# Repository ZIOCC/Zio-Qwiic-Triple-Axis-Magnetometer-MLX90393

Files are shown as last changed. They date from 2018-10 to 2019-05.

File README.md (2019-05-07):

# Zio Qwiic Triple Axis Magnetometer (MLX90393)

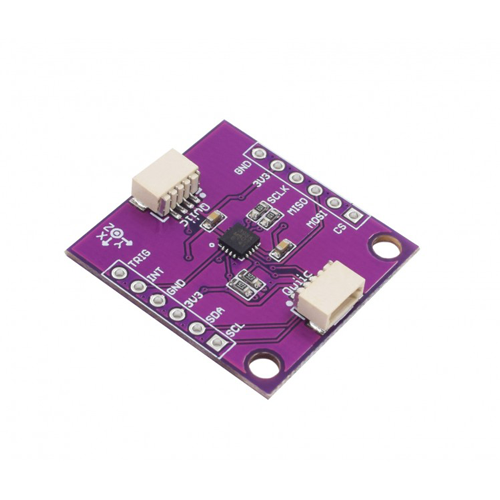
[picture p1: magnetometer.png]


> This product can be available for purchase [here](https://www.smart-prototyping.com/Zio-QwiIc-Triple-Axis-Magnetometer-MLX90393).

#### Description

This ZIO Qwiic board can be used as one of the Four Great Inventions: the compass. The board is a triple-axis magnetometer compass used to detect magnetic forces, mostly used to detect magnetic North. 
But magnetometers have many other uses such as detecting magnetic materials. 
 
The board features a MLX90393 sensor that incorporates both I2C and, able to sense a wide range of fields from small ones such as Earth’s magnetic field to larger magnetic fields. But the compass is not the only application for it, it can also be used for non-contact HMI applications (such as rotary knobs and joysticks), home security, liquid level sensing, position sensing and magnetic fingerprint detection. 
 
The resolution rate for the sensor is 0.161µ with an operating voltage range of 2.2V to 3.6V at 100µA. 
In addition, the I2C address can be changed thanks to the jumper pads on the back of the board (A0/ A1)  and the mode can also be changed to SPI thought the jumper pads. 

#### Specification

* Operation Voltage: 2.2V to 3.3V
* Relative Humidity: ±2%
* Temperature: ±0.3 °C
* IC: MLX90393
* I2C address: 0x0C, 0x0D, 0x0E, 0x0F (Default: 0x0C)
* Dimensions: 25.5 x 26.8mm
* Weight: 1.6g

#### Links

* [PCB source file (eagle file, schematic, Gerber files)](https://github.com/ZIOCC/Zio-Qwiic-Triple-Axis-Magnetometer-MLX90393)
* [MLX90393 Datasheet](https://cdn.sparkfun.com/assets/e/e/f/2/7/MLX90393-Datasheet-Melexis.PDF)
* [Library Code](https://github.com/tedyapo/arduino-MLX90393)

> ###### About Zio
> Zio is a new line of open sourced, compact, and grid layout boards, fully integrated for Arduino and Qwiic ecosystem. Designed ideally for wearables, robotics, small-space limitations or other on the go projects. Check out other awesome Zio products [here](https://www.smart-prototyping.com/Zio).

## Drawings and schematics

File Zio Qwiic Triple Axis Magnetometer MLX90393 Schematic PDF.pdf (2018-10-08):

# +3V3INT

1 | 2 | 3 | 4

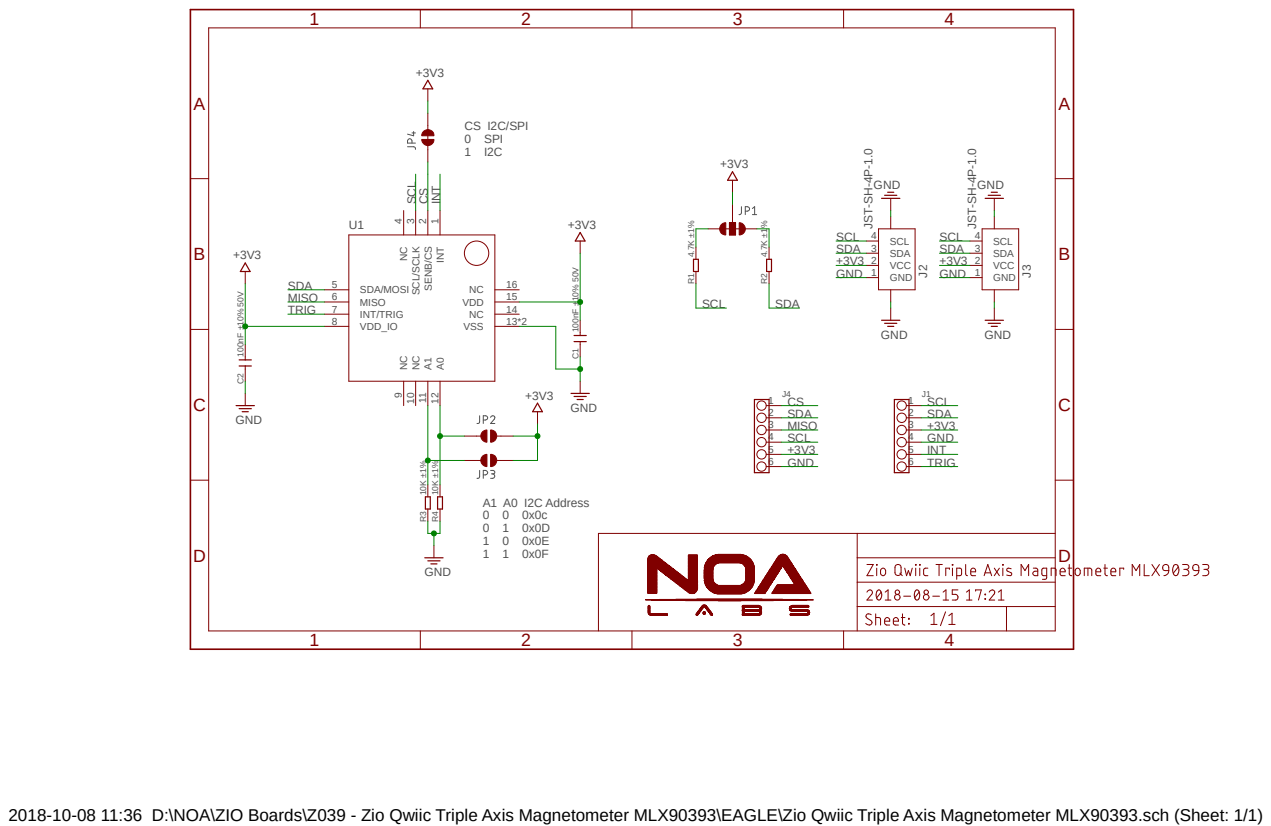
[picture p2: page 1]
A1 A0 I2C Address 0 0 0x0c 0 1 0x0D 1 0 0x0E 1 1 0x0F; CS I2C/SPI 0 SPI 1 I2C; GND; GND 4.7K ±1%; 100nF ±10% ⁵⁰V; GND¹⁰⁰nF ±10% ⁵⁰V; 1 SENB/CS; 2 SCL/SCLK; SDA/MOSI 5 MISO 6 INT/TRIG 7; VDD_IO 8; VSS; 14 VDD; GND 1; VCC 2; SDA 3; SCL 4; J3 JST⁻SH⁻⁴P⁻¹.0; J2 JST⁻SH⁻⁴P⁻¹.0 R¹; SCL; SCL SCL; SDA; +3V3 INT; INT; MISO; TRIG; TRIG CS

2018-10-08 11:36 D:\NOA\ZIO Boards\Z039 - Zio Qwiic Triple Axis Magnetometer MLX90393\EAGLE\Zio Qwiic Triple Axis Magnetometer MLX90393.sch (Sheet: 1/1)

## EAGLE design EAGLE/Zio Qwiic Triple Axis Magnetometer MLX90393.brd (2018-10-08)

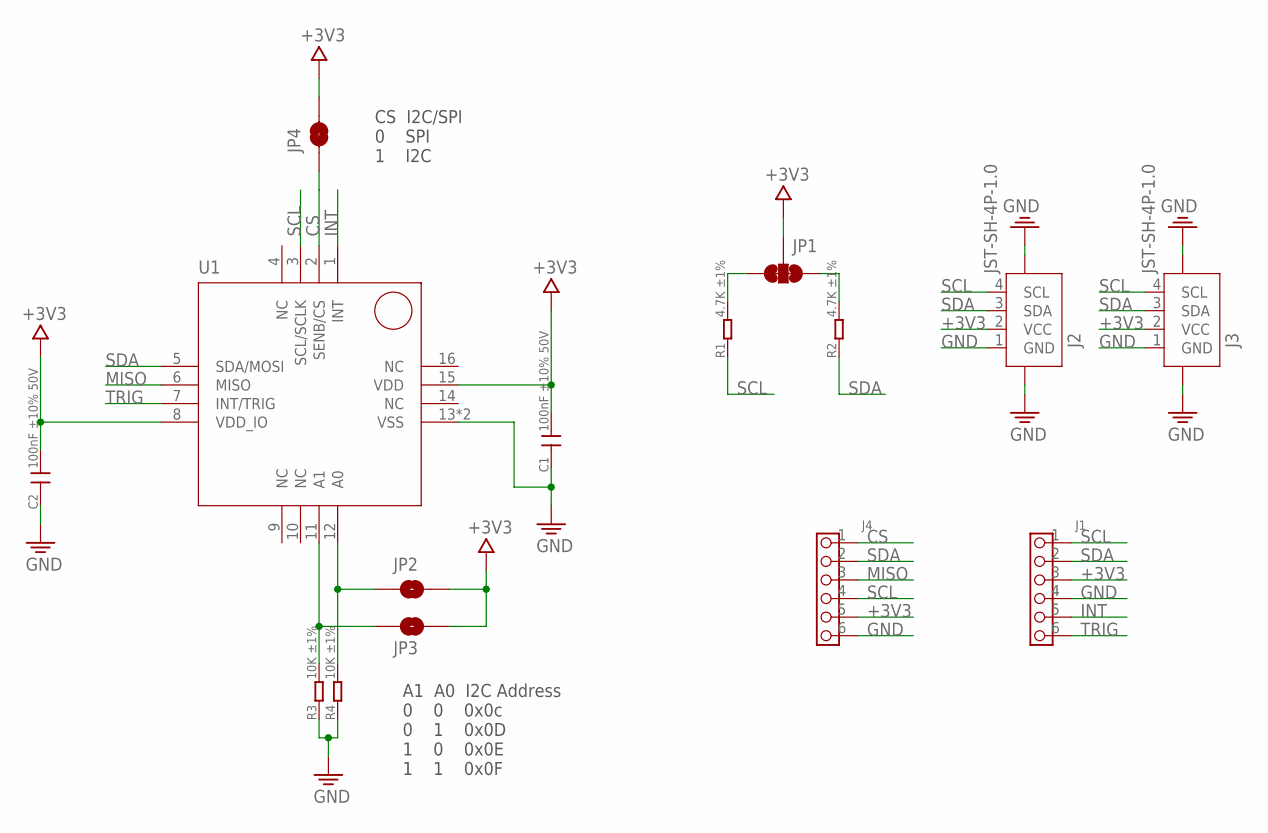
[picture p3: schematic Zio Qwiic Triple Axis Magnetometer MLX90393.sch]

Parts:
C1, C2: 100nF ±10% 50V; C0603
J1, J4: HEADER-6P-60/35MIL; 6P-2.54-60/35MIL
J2, J3: JST-SH-4P-1.0; JST-SH-4P
JP1: SMT-JUMPER_3_2-NC_TRACE
JP2, JP3: JUMPER-SMT_2_NC_PASTE_NOCREM; SMT-JUMPER_2_NC_PASTE_SILK_NOCREM
JP4: JUMPER-SMT_2_NC_TRACE; SMT-JUMPER_2_NC_TRACE
R1, R2: 4.7K ±1%; R0603
R3, R4: 10K ±1%; R0603
U1: MLX90393; QFN16-3*3

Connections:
+3V3: C1.2, C2.2, J1.3, J2.2 (VCC), J3.2 (VCC), J4.5, JP1.2, JP2.2, JP3.2, JP4.2, U1.8 (VDD_IO), U1.15 (VDD)
CS: J4.1, JP4.1, U1.2 (SENB/CS)
GND: C1.1, C2.1, J1.4, J2.1 (GND), J2.NC1 (5), J2.NC2 (6), J3.1 (GND), J3.NC1 (5), J3.NC2 (6), J4.6, R3.1, R4.1, U1.13 (VSS), U1.PAD (VSS)
INT: J1.5, U1.1 (INT)
MISO: J4.3, U1.6 (MISO)
unnamed: JP3.1, R3.2, U1.11 (A1)
unnamed: JP2.1, R4.2, U1.12 (A0)
unnamed: JP1.3, R1.2
unnamed: JP1.1, R2.2
SCL: J1.1, J2.4 (SCL), J3.4 (SCL), J4.4, R1.1, U1.3 (SCL/SCLK)
SDA: J1.2, J2.3 (SDA), J3.3 (SDA), J4.2, R2.1, U1.5 (SDA/MOSI)
TRIG: J1.6, U1.7 (INT/TRIG)

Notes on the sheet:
A1 A0 I2C Address 0 0 0x0c 0 1 0x0D 1 0 0x0E 1 1 0x0F
CS I2C/SPI 0 SPI 1 I2C

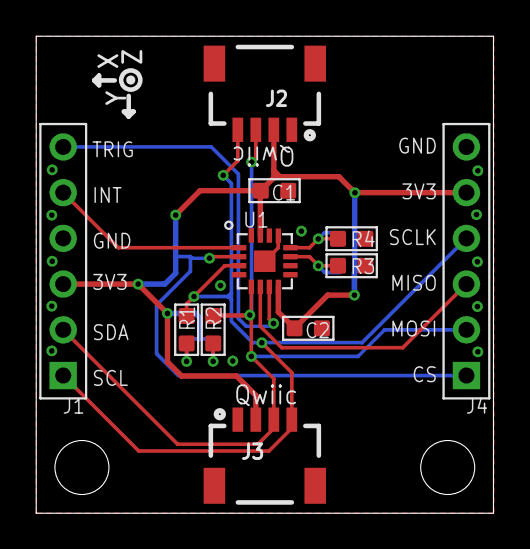
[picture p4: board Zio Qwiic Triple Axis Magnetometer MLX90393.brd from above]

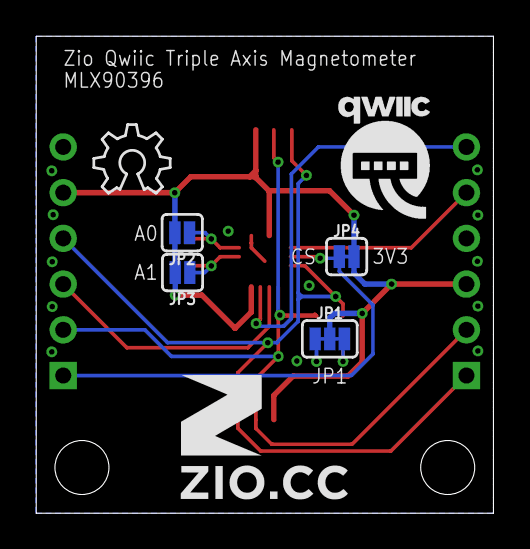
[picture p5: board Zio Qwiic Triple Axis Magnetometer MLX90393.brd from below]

Board: 2 copper layers, 25.4 x 26.5 mm, 18 parts (7 on the bottom side), 12 nets.

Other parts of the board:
U$6: 7MM
U$7: QWIIC-LOGO-MEDIUM
U$8: OSHW_6X150_NOTEXT
